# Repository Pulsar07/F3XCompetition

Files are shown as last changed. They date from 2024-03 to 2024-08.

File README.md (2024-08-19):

<div class="PageDoc">

<div class="header">

<div class="headertitle">

<div class="title">

F3X Competition is a tool to provide training measurements and analysis data for F3X model flight classes. 
At the moment it is limited to the F3B/F3G speed task and F3F task, but could be extended later on.

</div>

</div>

</div>

<div class="contents">

<div class="textblock">

# <span id="intro_sec_en" class="anchor"></span> Overview

In many F3X model flight classes there are distance and speed tasks, expecting the model to pass/cross a A- and B-line of a defined distance.
The passing and crossing is supervised by human helpers and signalled by pressing a button indication the valid pass or line crossing.

These procedures are supported by this F3X Competition tool (currently only the F3B/F3G speed task and F3F task).

The F3X Competition tool consist of two main parts:
* the BaseManager 
  * with a rotation/push button signaling device (Control and A-Line-Signal)
  including almost all logic and time measurement module
  * a display to provide flight data and user interface data
  * 2.4GHz radio link to communicate with the B-LineController
* the B-LineController
  * with a push button signaling device (B-Line-Signal)
  * 2.4GHz radio link to communicate with the BaseManager

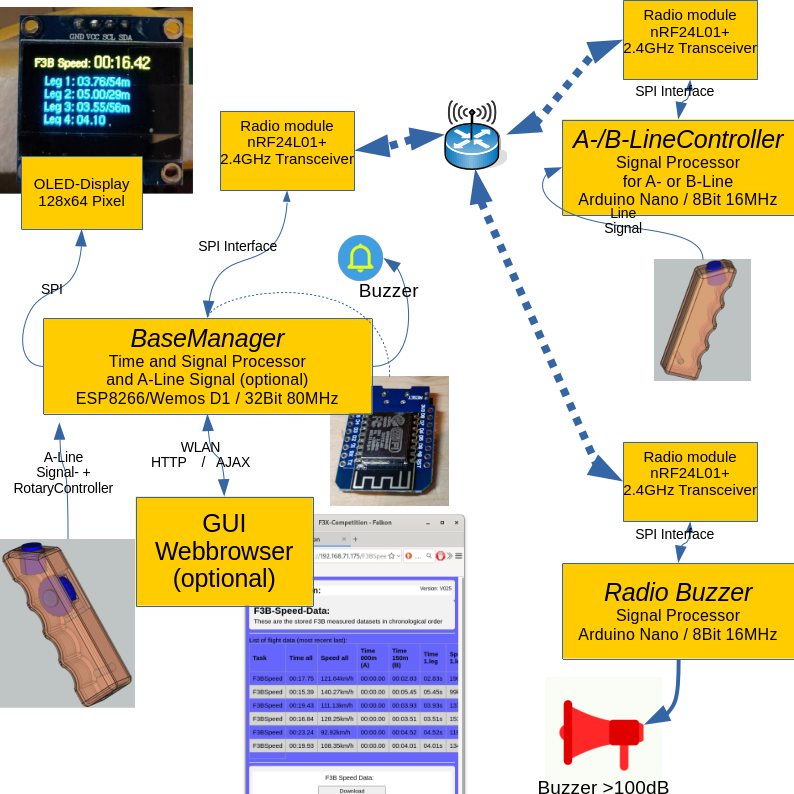
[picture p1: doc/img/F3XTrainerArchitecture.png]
Architektur


# <span id="features_sec_de" class="anchor"></span> Features
* 2.4GHz radio link using 1MHz channel between A-Line and B-Line
* time measurement with accurancy much better than 10ms
* accustic signal on A-Line
* F3B speed task is supported
  * overall time and detailed time and speed per leg is supported
  * dead distances behind the crossing lines are measured optionally and dead distances are supported
  * Loop mode: final signal of one task is the start signal for the next pilot
* F3F task is supported
  * overall time and detailed time and speed per leg is supported
  * dead distances behind the crossing lines are measured optionally and dead distances are supported
  * Loop mode: final signal of one task is the start signal for the next pilot
* integrated battery and charge HW with low battery warning
* firmware/data (BaseManager) can be updated over the air (OTA)
* BaseManager has a small OLED and rotary input device for on field operation
* BaseManager provides a Web-interface to be used for:
  * changes of settings
  * view, manage and download the saved trainings data
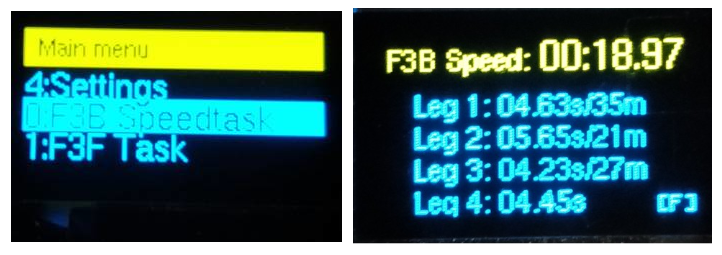
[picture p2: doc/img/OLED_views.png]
OLED


# <span id="hardware_sec_en" class="anchor"></span> Hardware
* Wemos D1 (BaseManager)
* Arduino Nano (B-LineController)
* 2.4GHz nRF24L01+ radio module
* BatteryShield
* LiIon Accu
* RotaryEncoder KY-040
* Push button
* OLED 128x64
* LED

</div>

</div>

</div>

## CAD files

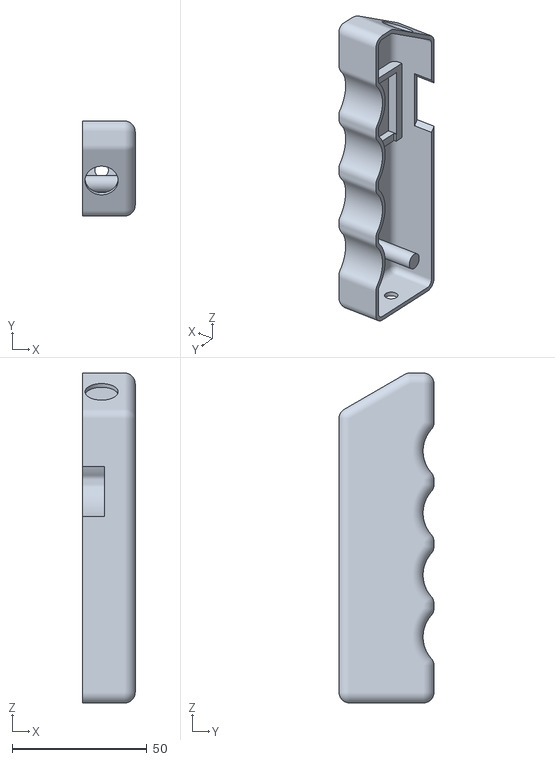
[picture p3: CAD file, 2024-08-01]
CAD/Griff-Griff-Halbschale-A-Line.stl
19.5 x 35.3 x 122.5

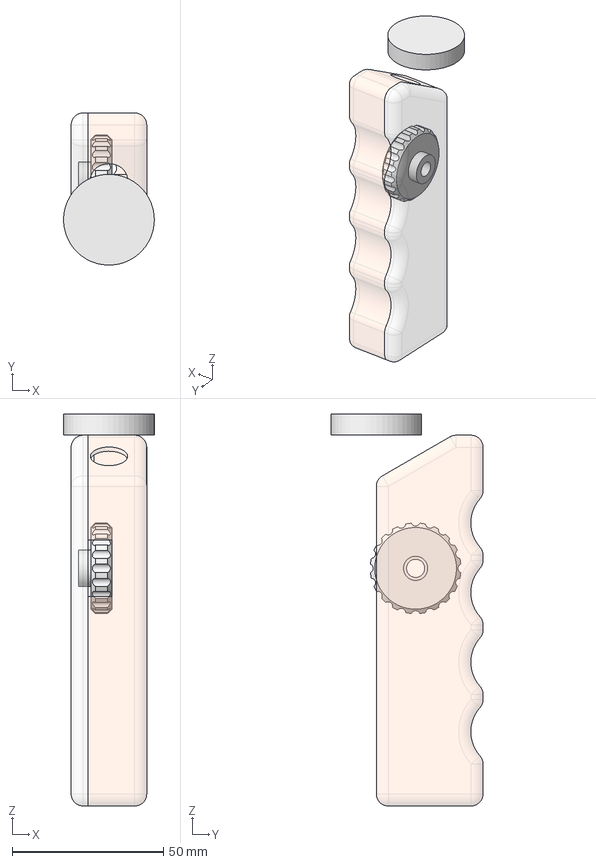
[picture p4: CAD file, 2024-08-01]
CAD/Griff.FCStd
30.0 x 50.3 x 129.5 mm
Griff-Deckel A-Line, mit Nut, Anbauteilen, Aussparungen
Encoder-Rad, roh
Drehrad, gefast, gelocht, geriffelt
Griff-Halbschale A-Line mit Aussparungen und Anbauteilen

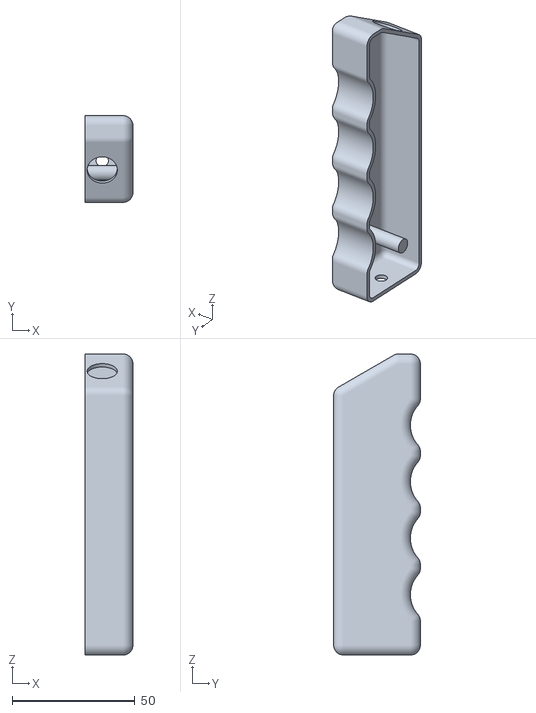
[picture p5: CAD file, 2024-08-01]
CAD/Griff-Griff-Halbschale-B-Line.stl
19.5 x 35.3 x 122.5

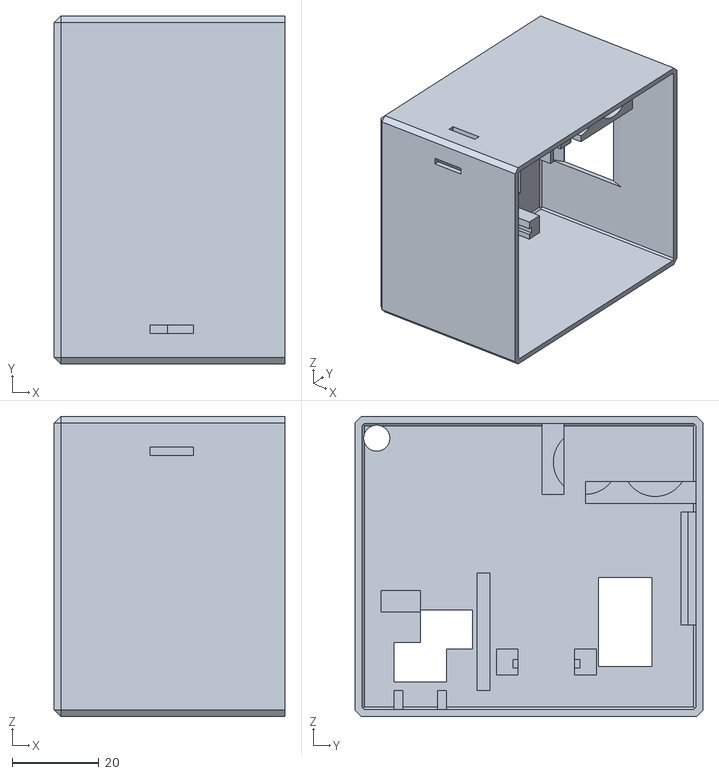
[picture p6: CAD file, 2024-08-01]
CAD/A-Line-Gehäuse.stl
53.0 x 80.0 x 69.0

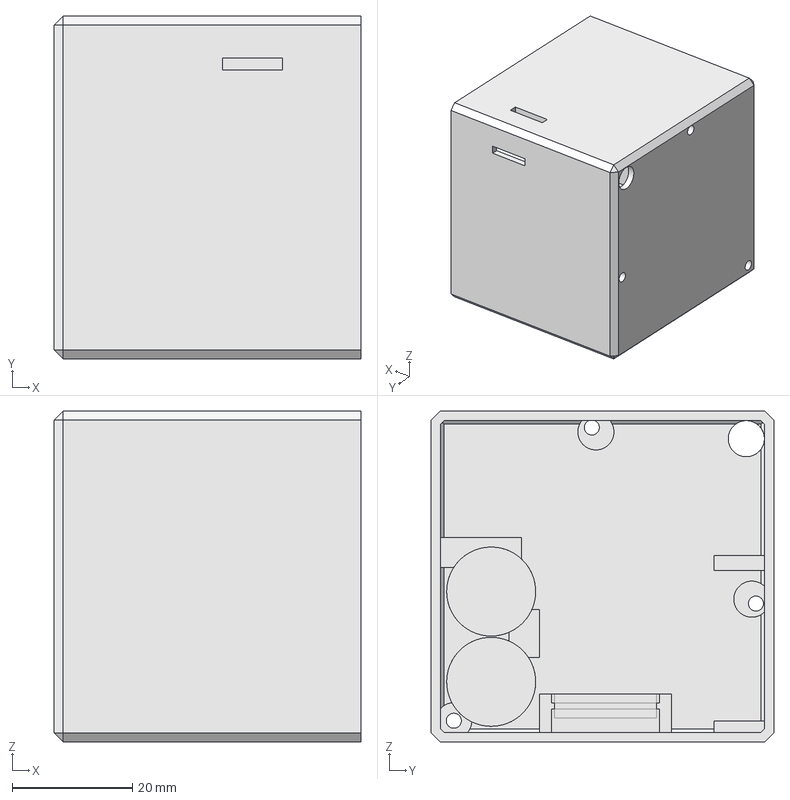
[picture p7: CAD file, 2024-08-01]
CAD/GehäuseF3XTrainer.FCStd
51.0 x 57.0 x 55.0 mm

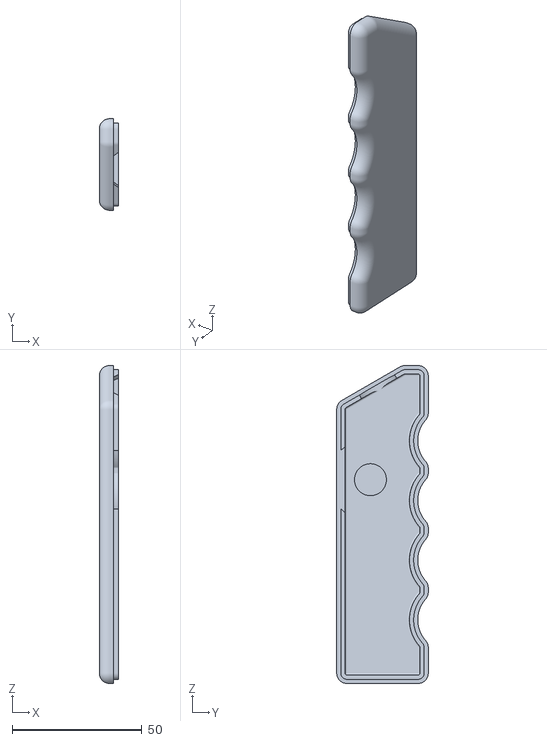
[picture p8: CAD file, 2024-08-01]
CAD/Griff-Deckel-A-Line.stl
7.50 x 35.3 x 122.5

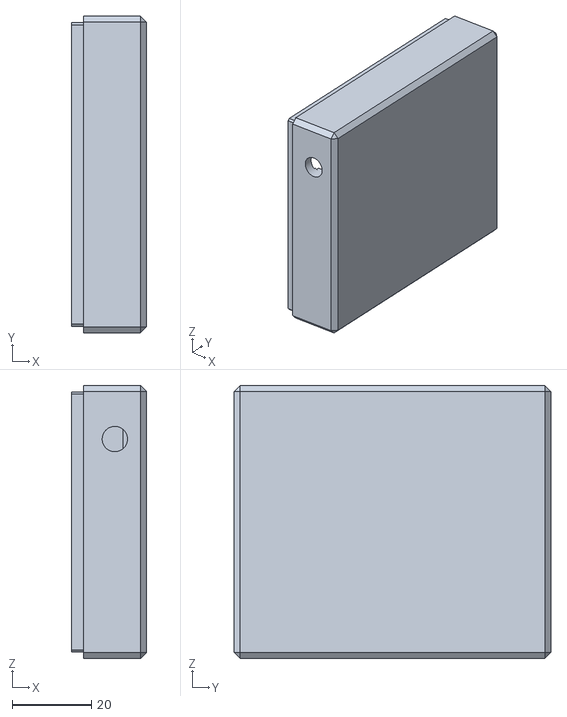
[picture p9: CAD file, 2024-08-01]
CAD/A-Line-Deckel.stl
19.0 x 80.0 x 69.0

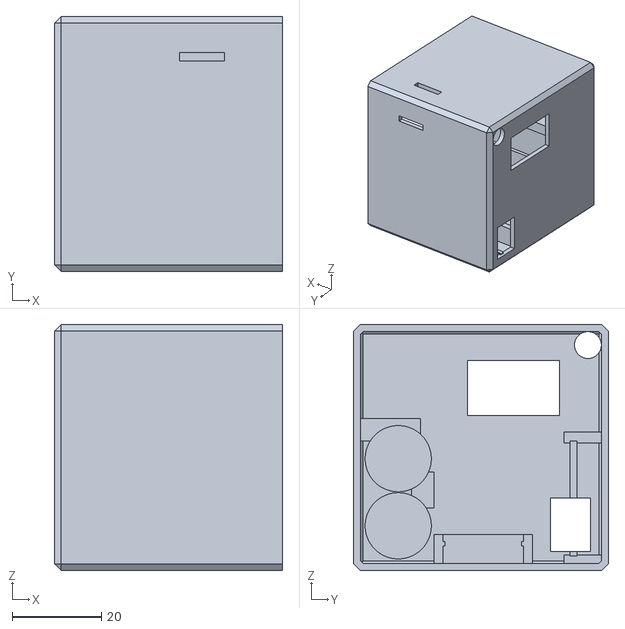
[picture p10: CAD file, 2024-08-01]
CAD/B-Line-Gehäuse.stl
51.0 x 57.0 x 55.0

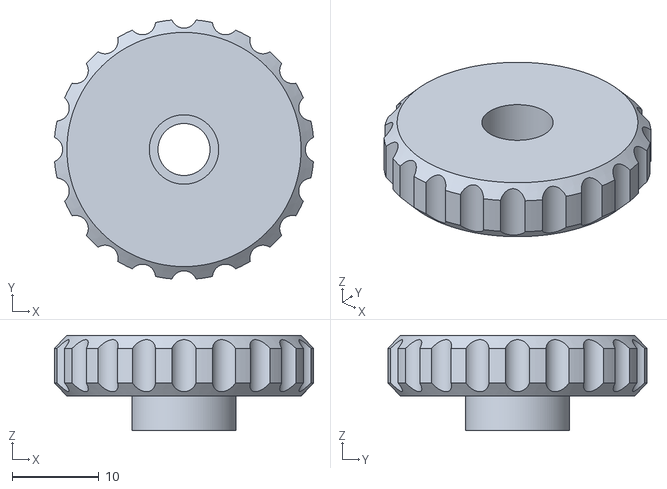
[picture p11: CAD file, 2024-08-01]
CAD/Griff-Drehrad-A-Line.stl
29.9 x 29.9 x 11.0

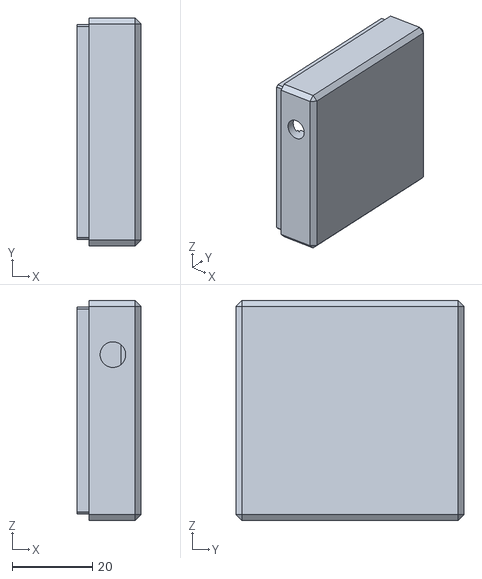
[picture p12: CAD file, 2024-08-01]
CAD/B-Line-Deckel.stl
16.0 x 57.0 x 55.0

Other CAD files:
CAD/RemoteBuzzer-Gehäuse.stl
CAD/Griff-Deckel.stl

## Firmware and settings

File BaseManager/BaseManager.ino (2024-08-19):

/**
 * \file BaseManager.ino
 *
 * \brief tool support trainings data measurement  
 *
 * \author Author: Rainer Stransky
 *
 * \copyright This project is released under the GNU Public License v3
 *          see https://www.gnu.org/licenses/gpl.html.
 * Contact: opensource@so-fa.de
 *
 */

#include <EEPROM.h>
#include <limits.h>
#include <ESP8266WiFi.h>
// #define USE_MDNS
#ifdef USE_MDNS
#include <ESP8266mDNS.h>
#endif
#include <WiFiUdp.h>
#include <ESP8266WebServer.h>
#include <ESP8266httpUpdate.h>
#include <Bounce2.h>
#include <Encoder.h>

#include "Logger.h"
#include "PinManager.h"
#include "LittleFS.h"
#include "Config.h"
#include "F3XFixedDistanceTask.h"
#include "F3XFixedDistanceTaskData.h"
#include "settings.h"

#define USE_RXTX_AS_GPIO  // for usage of rotary encoder instead of Serial

#define APP_VERSION "V035"

/*
Version History
 V011 19.10.2023: RS : pre-version: test web interface enhanced, minor bugs solved, OTA implemented
 V010 18.10.2023: RS : pre-version: initial version for F3B speed task and training data, with web interface only
 V023 26.02.2024: RS : firmware update triggerd on ABaseManager via Einstellungen->3:Update Firmw.;
 V024 08.03.2024: RS : pre version of RF24 channel and power setting via controller and OLED
 V025 13.03.2024: RS : A-line controller with rotary encoder, settings in EEPROM via OLED and Web.
 V026 13.03.2024: RS : Web-pages redesigned
 V027 15.03.2024: RS : Buzzer refactored to PinManager-class to support beep sequences for battery low warning
 V028 18.03.2024: RS : new speed start / back menu added
 V029 19.03.2024: RS : F3B Speed Tasktime is now a config item.
 V030 28.03.2024: RS : Refactoring F3BSpeedTask -> F3XFixedDistanceTask, more consistent time strings and units (CSV)
 V031 04.05.2024: RS : added support for a radio buzzer 
 V032 31.07.2024: RS : F3F Task added, Logger refactored, TaskData handling generalized, address schema of RFTransceiver fixed.
 V033 01.08.2024: RS : Support for F3X Loop Task, finalizing the course will start frame time of next starter automatically
 V034 02.08.2024: RS : nRF24 address scheme modified to support old versions of remote devices 
 V035 19.08.2024: RS : bugfix: buzzer settings not saved, added missing F3F A-Line flyover signal,  long 1.5s finish signals F3F+F3B, 
                       interpreation of F3F Tasktime is now: time between StartTaskSignal and launch time,
                       more precise naming of entities/files: BaseManager, LineController  
*/

/**
Feature list:
* Battery warning
* F3B Speed, F3F Task
*
* ...
*/

static const char myName[] = "BaseM";
static const char MYSEP_STR[] = "~~~";
static const char CMDSEP_STR[] = ",";

// Used Ports as as summary
/*
D0 : RF24-NRF24L01 CE (brown-white)
D1 : OLED-SSD1306 SCL
D2 : OLED-SSD1306 SDA 
D3 : RF24-NRF24L01 CNS (brown) 
D4 : Signalling Button A-Line
D5 : RF24-NRF24L01 SCK (blue-white) 
D6 : RF24-NRF24L01 MISO (green-white)
D7 : RF24-NRF24L01 MOSI (blue)
D8 : BUZZER / LED
D9/RX  : KY-040 Encoder - DT 
D10/TX : KY-040 Encoder - CLK

*/


#define PIN_RF24_CE       D0
#define PIN_OLED_SCL      D1
#define PIN_OLED_SDA      D2
#define PIN_RF24_CNS      D3
#define PIN_SIGNAL_A_LINE D4
#define PIN_RF24_SCK      D5
#define PIN_RF24_MISO     D6
#define PIN_RF24_MOSI     D7
#define PIN_BUZZER_OUT    D8
#define PIN_ENCODER_DT    D9
#define PIN_ENCODER_CLK   D10

#define PIN_BATTERY_IN    A0  // connected wiht R=100kOhm to support V > 3.2V

#define USE_BATTERY_IN_VOLTAGE
#define PERF_DEBUG

// #define NOBUZZ
#ifdef NOBUZZ
#pragma message ("BUZZER IS OFF !!!!!!!!!!!")
#endif
#define BUZZ_TIME_LONG   1500 // course finised
#define BUZZ_TIME_NORMAL  500 // normal turn
#define BUZZ_TIME_SHORT    100 // user info

#include <RFTransceiver.h>
RFTransceiver ourRadio(myName, PIN_RF24_CE, PIN_RF24_CNS); // (CE, CSN)



#ifdef USE_RXTX_AS_GPIO
Encoder ourRotaryEncoder(PIN_ENCODER_DT, PIN_ENCODER_CLK);
#endif

#define RE_MULITPLIER_SLOW 1
#define RE_MULITPLIER_NORMAL 5
long ourRotaryMenuPosition=0;
uint8_t ourRotaryEncoderMultiplier;
static boolean ourREState = true;
static int8_t ourREInversion = 1;
static long ourREOldPos  = 0;

static boolean ourLoopF3XTask = false;
static unsigned long ourLoopF3XPrevCourseTime = 0L;

enum BuzzerSetting {
  BS_ALL = 0, // both buzzers are active 
  BS_BASEMANAGER, // only direct connected BaseManager Buzzer 
  BS_REMOTE_BUZZER, // only remote radio buzzer
  BS_NONE, // no buzzers are active 
  BS_LAST,
};

static boolean ourIsTimeCriticalOperationRunning = false;

enum ToolContext {
  TC_F3XBaseMenu,
  TC_F3XSettingsMenu,
  TC_F3BSpeedTasktimeCfg,
  TC_F3FTasktimeCfg,
  TC_F3FLegLengthCfg,
  TC_F3XRadioChannelCfg,
  TC_F3XRadioPowerCfg,
  TC_F3XInfo,
  TC_F3XRadioInfo,
  TC_F3XMessage,
  TC_F3BSpeedMenu,
  TC_F3BSpeedTask,
  TC_F3FTaskMenu,
  TC_F3FTask,
  TC_F3BDistanceTask,
  TC_F3BDurationTask,
};

#define F3XCONTEXT_HISTORY_SIZE 5
class F3XContext {
  public:
    F3XContext(ToolContext aContext) {
      for (uint8_t i=0; i<F3XCONTEXT_HISTORY_SIZE; i++) {
        myContextHistory[i] = TC_F3XBaseMenu;
      }
      set(aContext);
    }
    void set(ToolContext aContext) {
      logMsg(LOG_MOD_SIG, INFO, String("set context:") + String(aContext));
      
      for (uint8_t i=0; i<F3XCONTEXT_HISTORY_SIZE-1; i++) {
        myContextHistory[i+1] = myContextHistory[i];
      }
      myContextHistory[0] = aContext;
  
      myInfoString="";
      myInfoInt = 0;
      myInfoFloat = 0.0f;
      myIsTaskRunning = false;
    }
    void back() {
      for (uint8_t i=0; i<F3XCONTEXT_HISTORY_SIZE-1; i++) {
        myContextHistory[i] = myContextHistory[i+1];
      }
      myContextHistory[F3XCONTEXT_HISTORY_SIZE-1] = TC_F3XBaseMenu;

      logMsg(LOG_MOD_SIG, INFO, String("back context:") + String(get()));
    }
    ToolContext get() {
      return myContextHistory[0];
    }
    String getInfoString() {
      return myInfoString;
    }
    float getInfoFloat() {
      return myInfoFloat;
    }
    int getInfoInt() {
      return myInfoInt;
    }
    void setInfo(float aArg) {
      myInfoFloat = aArg;
    }
    void setInfo(int aArg) {
      myInfoInt = aArg;
    }
    void setInfo(String aArg) {
      myInfoString = aArg;
    }
  private:
    ToolContext myContextHistory[F3XCONTEXT_HISTORY_SIZE];
    float myInfoFloat;
    int myInfoInt;
    String myInfoString;
    bool myIsTaskRunning;
};

F3XContext ourContext(TC_F3XInfo);

// TC_F3XBaseMenu
const char* ourF3XBaseMenuName = "Main menu";
const char* ourF3XBaseMenu0 = "0:F3B Speedtask";
const char* ourF3XBaseMenu1 = "1:F3F Task";
const char* ourF3XBaseMenu2 = "2:Info";
const char* ourF3XBaseMenu3 = "3:Radio-Info";
const char* ourF3XBaseMenu4 = "4:Settings";
const char* ourF3XBaseMenuItems[] = {ourF3XBaseMenu0, ourF3XBaseMenu1, ourF3XBaseMenu2, ourF3XBaseMenu3, ourF3XBaseMenu4};
const uint8_t ourF3XBaseMenuSize = sizeof(ourF3XBaseMenuItems) / sizeof(char*);;

// TC_F3XSettingsMenu
const char* ourSettingsMenuName = "Settings";
const char* ourSettingsMenu0 = "0:F3B Speed Ttime";
const char* ourSettingsMenu1 = "1:F3F Ttime";
const char* ourSettingsMenu2 = "2:F3F LegLength";
const char* ourSettingsMenu3 = "3:Buzzers setup";
const char* ourSettingsMenu4 = "4:Competition setup";
const char* ourSettingsMenu5 = "5:Radio channel";
const char* ourSettingsMenu6 = "6:Radio power";
const char* ourSettingsMenu7 = "7:Display invert";
const char* ourSettingsMenu8 = "8:Rotary button inv.";
const char* ourSettingsMenu9 = "9:Update firmware";
const char* ourSettingsMenu10 = "10:Update filesystem";
const char* ourSettingsMenu11 = "11:WiFi on/off";
const char* ourSettingsMenu12 = "12:Save settings";
const char* ourSettingsMenu13 = "13:Main menu";
const char* ourSettingsMenuItems[] = {ourSettingsMenu0, ourSettingsMenu1, ourSettingsMenu2, ourSettingsMenu3, ourSettingsMenu4, ourSettingsMenu5, ourSettingsMenu6, ourSettingsMenu7, ourSettingsMenu8, ourSettingsMenu9, ourSettingsMenu10, ourSettingsMenu11, ourSettingsMenu12, ourSettingsMenu13};
const uint8_t ourSettingsMenuSize = sizeof(ourSettingsMenuItems) / sizeof(char*);

// TC_F3BSpeedMenu
const char* ourF3BSpeedMenuName = "F3B Speed";
const char* ourF3BSpeedMenu0 = "0:Start Task";
const char* ourF3BSpeedMenu1 = "1:Loop Task";
const char* ourF3BSpeedMenu2 = "2:Back";
const char* ourF3BSpeedMenuItems[] = {ourF3BSpeedMenu0, ourF3BSpeedMenu1, ourF3BSpeedMenu2};
const uint8_t ourF3BSpeedMenuSize = sizeof(ourF3BSpeedMenuItems) / sizeof(char*);

// TC_F3FTaskMenu
const char* ourF3FTaskMenuName = "F3F Task";
const char* ourF3FTaskMenu0 = "0:Start Task";
const char* ourF3FTaskMenu1 = "1:Loop Task";
const char* ourF3FTaskMenu2 = "2:Back";
const char* ourF3FTaskMenuItems[] = {ourF3FTaskMenu0, ourF3FTaskMenu1, ourF3FTaskMenu2};
const uint8_t ourF3FTaskMenuSize = sizeof(ourF3FTaskMenuItems) / sizeof(char*);


#include "F3XRemoteCommand.h"

#define OLED
#ifdef OLED
#include <U8g2lib.h>
/*
// TFT Display  ST7735S
//
https://github.com/olikraus/u8g2/wiki/u8g2setupcpp#introduction
SCL D1
SDA D2
U8G2_SSD1306_128X64_NONAME_1_HW_I2C(rotation, [reset [, clock, data]]) [page buffer, size = 128 bytes]
U8G2_SSD1306_128X64_NONAME_2_HW_I2C(rotation, [reset [, clock, data]]) [page buffer, size = 256 bytes]
U8G2_SSD1306_128X64_NONAME_F_HW_I2C(rotation, [reset [, clock, data]]) [full framebuffer, size = 1024 bytes]
*/

// U8G2_SSD1306_128X64_NONAME_1_HW_I2C ourOLED(U8G2_R0, U8X8_PIN_NONE, D1, D2);
// #define SSD1306_AZ_Delivery
// supported OLEDs
// OLED 0.96" SSD1306   0,96 Zoll OLED SSD1306 Display I2C 128 x 64 Pixel / AZ-Delivery
#define OLED_FULL_BUFFER
#ifdef OLED_FULL_BUFFER
U8G2_SSD1306_128X64_NONAME_F_HW_I2C ourOLED(U8G2_R0, U8X8_PIN_NONE, PIN_OLED_SCL /*SCL*/, PIN_OLED_SDA /*SDA*/);  
#else
U8G2_SSD1306_128X64_NONAME_1_HW_I2C ourOLED(U8G2_R0, U8X8_PIN_NONE, PIN_OLED_SCL /*SCL*/, PIN_OLED_SDA /*SDA*/);  
#endif
// OLED xxx
// U8G2_SSD1309_128X64_NONAME2_1_HW_I2C ourOLED(U8G2_R0, U8X8_PIN_NONE, PIN_OLED_SCL /*SCL*/, PIN_OLED_SDA /*SDA*/);  

#endif

#define OTA
#ifdef OTA
#include <ArduinoOTA.h>
#endif
 

IPAddress ourApIp(192,168,4,1);
IPAddress ourNetmask(255,255,255,0);
ESP8266WebServer ourWebServer(80);
unsigned long ourSecond = 0;

static configData_t ourConfig;
F3XFixedDistanceTask ourF3BSpeedTask(F3XFixedDistanceTask::F3BSpeedType);
F3XFixedDistanceTaskData ourF3BTaskData(&ourF3BSpeedTask);
F3XFixedDistanceTask ourF3FTask(F3XFixedDistanceTask::F3FType);
F3XFixedDistanceTaskData ourF3FTaskData(&ourF3FTask);
F3XFixedDistanceTask* ourF3XGenericTask = nullptr;
unsigned long ourWlanRoundTripTime=0;
unsigned long ourRadioRequestTime=0;
float ourRadioRoundTripTime=0;
uint8_t ourRadioRequestArg=0;
uint16_t ourRadioCycleSendCnt=0;
uint8_t ourRadioPacketsLossPercent=0;
uint16_t ourRadioCycleRecvCnt=0;
uint16_t ourRadioRoundTripMissed=0;
uint16_t ourRadioRoundtripIdx=0;
int8_t ourRadioPower=-1;
int8_t ourRadioChannel=-1;
int8_t ourRadioDatarate=-1;
boolean ourRadioAck=true;
boolean ourRadioSendSettings=false;
float ourRadioQuality=0.0f;
uint16_t ourRadioStatePacketsMissed=0;
uint16_t ourRadioSignalRoundTrip=0;
boolean ourStartupPhase=true;
F3XRemoteCommand ourRemoteCmd;
uint16_t ourBatteryAVoltage;
uint16_t ourBatteryBVoltage;
uint16_t ourBatteryBVoltageRaw;
uint16_t ourBatteryRemoteSignalRaw;
unsigned long ourTimedReset = 0;
unsigned long ourDialogTimer=0;
String ourDialogString="";

Bounce2::Button ourPushButton = Bounce2::Button();
PinManager ourBuzzer(PIN_BUZZER_OUT);

// =========== some function forward declarations ================

void updateOLED(unsigned long aNow, bool aForce);
void updateOLED(unsigned long aNow);
#ifdef USE_RXTX_AS_GPIO
void resetRotaryEncoder(long aPos=0);
#endif
uint8_t getModulo(long aDivident, uint8_t aDivisor);
void forceOLED(uint8_t aLevel, String aMessage);
void forceOLED(String aHead, String aMessage);
void setDefaultConfig();
void saveConfig();
void takeOLEDScreenshot();


void restartMCs(uint16_t aDelay, bool aRestartOnlyBLine=false) {
  ourRadio.transmit(ourRemoteCmd.createCommand(F3XRemoteCommandType::CmdRestartMC)->c_str(), 20);
  ourRadio.setWritingPipe(2);
  ourRadio.transmit(ourRemoteCmd.createCommand(F3XRemoteCommandType::CmdRestartMC)->c_str(), 20);
  ourRadio.setWritingPipe(0);
  if (!aRestartOnlyBLine) {
    // force a restart of ourself
    ourTimedReset = millis() + aDelay;
  }
}


/*
* send a RF24 command to the 2. pipe (radioBuzzer) 
*/
void radioBuzzer(uint16_t aDura) {
  // logMsg(INFO, String(F("=====> radioBuzzer on:")) + String(aDura)); 
  ourRadio.setWritingPipe(2);
  unsigned long a = millis();
  boolean sendSuccess = ourRadio.transmit(ourRemoteCmd.createCommand(F3XRemoteCommandType::RemoteSignalBuzz, String(aDura))->c_str(), 4);

  if (!sendSuccess) {
    logMsg(LOG_MOD_RADIO, ERROR, String(F("sending RemoteSignalBuzz NOT successsfull. Retransmissions: ")) 
      + String(ourRadio.getRetransmissionCount()));
  }
  logMsg(LOG_MOD_RADIO, INFO, String(F("sending RemoteSignalBuzz in: ") + String((millis() - a)))); 
  ourRadio.setWritingPipe(0);
}

void signalBuzzing(uint16_t aDuration) {
  logMsg(LOG_MOD_SIG, INFO, "ABM: signalBuzzing: " + String(aDuration));
  switch (ourConfig.buzzerSetting) {
    case BS_ALL: // both buzzers are active 
      radioBuzzer(aDuration);
      ourBuzzer.on(aDuration);
      break;
    case BS_BASEMANAGER: // only direct connected BaseManager Buzzer 
      ourBuzzer.on(aDuration);
      break;
    case BS_REMOTE_BUZZER: // only remote radio buzzer
      radioBuzzer(aDuration);
      break;
    case BS_NONE: // no buzzers are active 
      break;
  }
}

void signalAListener() {
  logMsg(LOG_MOD_SIG, INFO, "ABM: signalAListener");
  if (ourF3XGenericTask->getTaskState() == F3XFixedDistanceTask::TaskFinished) {
    // looong signal at final A-Line overfly signalling 1500ms
    signalBuzzing(BUZZ_TIME_LONG);
    if (ourF3XGenericTask->getLoopTasksEnabled()) {
      ourF3XGenericTask->stop();
      ourF3XGenericTask->start();
    }
  } else {
    // default signalling 500ms
    signalBuzzing(BUZZ_TIME_NORMAL);
  }
  switch(ourF3XGenericTask->getType()) {
    case F3XFixedDistanceTask::F3BSpeedType:
      if (ourF3XGenericTask->getTaskState() == F3XFixedDistanceTask::TaskFinished) {
        ourF3BTaskData.writeData();
      }
      break;
    case F3XFixedDistanceTask::F3FType:
      if (ourF3XGenericTask->getTaskState() == F3XFixedDistanceTask::TaskFinished) {
        ourF3FTaskData.writeData();
      }
      break;
  }
}

void signalBListener() {
  logMsg(LOG_MOD_SIG, INFO, "signalBListener");
  signalBuzzing(BUZZ_TIME_NORMAL);
}

/**
  return a leg time literal with the format 12.23s/43m  
*/
char* getLegTimeStr(unsigned long aLegTime,  unsigned long aDelay, uint8_t aDistance, char aSeparator='/') {
  static char buffer[25];
  if (aLegTime != F3X_TIME_NOT_SET) {
    sprintf(&buffer[0],"%02d.%02ds", aLegTime / 1000, aLegTime/10%100); // len=8+7=15
  }
  if (aDelay != 0) {
    sprintf(&buffer[strlen(buffer)],"%c%dm", aSeparator, aDistance); // len=15+8=23+1
  }
  return buffer;
}


/**
  return a time literal with the format Seconds.Centies 12.23s
*/
char* getSCTimeStr(unsigned long aTime, bool aShowUnit=false ) {
  static char buffer[10];
  unsigned long theTime = aTime;
  if (aTime == F3X_TIME_NOT_SET) {
    theTime = 0UL;
  }
  String format= F("%02d.%02d");
  if (aShowUnit) {
    format= F("%02d.%02ds");
  }
  sprintf(&buffer[0],format.c_str(), theTime/1000, theTime/10%100); 
  return buffer;
}


#ifdef OLED
const uint8_t *oledFontLarge;
const uint8_t *oledFontBig;
const uint8_t *oledFontNormal;
const uint8_t *oledFontSmall;
const uint8_t *oledFontTiny;


void setupOLED() {
  ourOLED.begin();
  int oledDisplayHeight = ourOLED.getDisplayHeight(); 
  int oledDisplayWidth = ourOLED.getDisplayWidth(); 
  logMsg(INFO, F("init OLED display: ") + String(oledDisplayWidth) + String(F("x")) + String(oledDisplayHeight)); 
  oledFontLarge  = u8g2_font_helvR12_tr;
  oledFontBig    = u8g2_font_helvR10_tr;
  oledFontNormal = u8g2_font_helvR08_tr;
  oledFontSmall  = u8g2_font_5x7_tr;
  oledFontTiny   = u8g2_font_4x6_tr;
  forceOLED(0, String(F("OLED ok")));
}
#endif

void setupRadio() {
  logMsg(INFO, F("setup RCTTransceiver/nRF24L01")); 
  ourRadio.begin(RFTransceiver::F3XBaseManager);  // set 0 for BaseManager
  logMsg(INFO, F("setup for RCTTransceiver/nRF24L01 successful")); 

  // in the RFTransceiver implementation the default values for the radio settings are defined 
  // for A- and B-Line Manager (Channel:110/Power:HIGH/Datarate:RF24_250KBPS/Ack:true)
  // if the user is changing radio settings, they are save in the EEPROM config ourConfig/loadConfig/saveConfig
  // at startup, these config value are NOT used, to provide in any case a commont radio setting for both sides.
  // Only the BaseManager, stores changed radio settings, boots with the default settings starts a communication with the 
  // B-Line-Manager and sends changed settings via radio  

  ourRadioPower=ourRadio.getPower();
  ourRadioChannel=ourRadio.getChannel();
  ourRadioDatarate = ourRadio.getDataRate();
  ourRadioAck=ourRadio.getAck();

  if (   ourRadioChannel != ourConfig.radioChannel
      || ourRadioPower   != ourConfig.radioPower
    ) {
    ourRadioChannel = ourConfig.radioChannel;
    ourRadioPower = ourConfig.radioPower;
    // force a radio data  CmdSetRadio packets to B-Line
    ourRadioSendSettings=true;
  }
  logMsg(LOG_MOD_WEB, INFO, F("RF24-cfg: (c/p)") + String(ourConfig.radioChannel) + String(F("/")) + String(ourConfig.radioPower)); 

  forceOLED(0, ("RF24 radio started"));
}


void setupLittleFS() {
  if(!LittleFS.begin()){
    logMsg(DEBUG, F("LittleFS: An Error has occurred while mounting LittleFS"));
    forceOLED(0, ("FS not ok"));
    return;
  }
  forceOLED(0, ("FS ok"));
}



void setupWiFi() {
  // first try to connect to the stored WLAN, if this does not work try to
  // start as Access Point
  // strncpy(ourConfig.wlanSsid , DEF_SSID, CONFIG_SSID_L);
  // strncpy(ourConfig.wlanPasswd, DEF_PSK, CONFIG_PASSW_L);
  // strncpy(ourConfig.apPasswd, "12345678", CONFIG_PASSW_L) ;
  if (!ourConfig.wifiIsActive) {
    WiFi.mode(WIFI_OFF) ; // client mode only
    forceOLED(0, (String("WiFi: inactive")));
    delay(1500);
    return;
  }

  if (String(ourConfig.wlanSsid).length() != 0 ) {
    WiFi.persistent(false);
    WiFi.mode(WIFI_STA) ; // client mode only
    WiFi.begin(ourConfig.wlanSsid, ourConfig.wlanPasswd);

    logMsg(DEBUG, String(F("Connecting to ")) + ourConfig.wlanSsid);
    int connectCnt = 0;
    while (WiFi.status() != WL_CONNECTED && connectCnt++ < 20) {
      delay(500);
    }
  }

  if (WiFi.status() == WL_CONNECTED) {
    logMsg(INFO, F("success!"));
    logMsg(LOG_MOD_WEB, INFO, F("IP Address is: ") + WiFi.localIP().toString());
    forceOLED(0, (String("WiFi: ") + WiFi.localIP().toString()));
  } else {
    logMsg(INFO, String(F("cannot connect to SSID :")) + ourConfig.wlanSsid);
    WiFi.mode(WIFI_AP) ; // client mode only
  }
  if (WiFi.status() != WL_CONNECTED) {
    logMsg(INFO, String(F("Starting WiFi Access Point with  SSID: ")) + ourConfig.apSsid);
      forceOLED(0, String(("Start WiFi-AP: ") + String(ourConfig.apSsid)));
      delay(1000);
    WiFi.softAPConfig(ourApIp, ourApIp, ourNetmask);    //Password length minimum 8 char
    boolean res = WiFi.softAP(ourConfig.apSsid, ourConfig.apPasswd, 3, 0, 1);    //Password length minimum 8 char, channel, hidden, #clients
    if(res ==true) {
      IPAddress myIP = WiFi.softAPIP();
      logMsg(INFO, F("AP setup done!"));
      logMsg(INFO, String(F("Host IP Address: ")) + myIP.toString());
      logMsg(INFO, String(F("Please connect to SSID: ")) + String(ourConfig.apSsid) + String(F(", PW: ")) + ourConfig.apPasswd);
      forceOLED(0, String(F("WiFi AP-SSID: ")) + String(ourConfig.apSsid) + String(F(" IP: ")) + myIP.toString());
      delay(1000);
    } else {
      forceOLED(0, String("WiFi: not started"));
      delay(1000);
    }
  }
  #ifdef USE_MDNS
  if (!MDNS.begin("f3x", WiFi.localIP())) {             
    logMsg(LOG_MOD_NET, ERROR, "Error starting mDNS");
  } else {
    logMsg(LOG_MOD_NET, INFO, "mDNS started");
  }
  #endif
}

String getWiFiIp(String* ret) {
  if (WiFi.status() == WL_CONNECTED) {
    ret->concat(WiFi.localIP().toString());
  } else {
    ret->concat(String(ourConfig.apSsid));
    ret->concat(String(F("/")));
    ret->concat(WiFi.softAPIP().toString());
  }
  return *ret;
}

// End: WIFI WIFI WIFI

// Start: WEBSERVER WEBSERVER WEBSERVER 
// =================================
// web server functions
// =================================

const int led = 13;
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
void loop()
{
  static unsigned long next = 0;
  static unsigned long lastslow = 0;
  unsigned long now = millis();

  #ifdef PERF_DEBUG
  unsigned long lnow;
  boolean isSlow = false;
  if ((now - lastslow) > 200) {
    logMsg(LOG_MOD_PERF, WARNING, String(F("slow last loop:")) + String(now-lastslow));
    isSlow = true;
  }
  lastslow = now;
  #endif

  perfCheck(&updatePushButton, "time push button", now);

  perfCheck(&updateBuzzer, "time buzzer", now);

  perfCheck(&updateF3XTask, "time speedtask", now);

  perfCheck(&updateRadio, "time radio", now);

  perfCheck(&updateWebServer, "time webserver", now);

  perfCheck(&updateBatterySupervision, "time battery supervision", now);

  perfCheck(&updateTimedEvents, "time timedEvents", now);
  
  #ifdef OLED 
  perfCheck(&updateOLED, "time oled display", now);
  #endif

  #ifdef USE_RXTX_AS_GPIO
  perfCheck(&updateRotaryEncoder, "time rotary encoder", now);
  #endif


  if (WiFi.status() == WL_CONNECTED) {
    #ifdef OTA
    ArduinoOTA.handle();
    #endif
    #ifdef USE_MDNS
    MDNS.update();
    #endif
  }

  if (now >= next) {
    ourSecond++;
    next = now + 1000;
  } else {
    return;
  }

  if (ourSecond > 5) {
    ourStartupPhase = false;
  }
}

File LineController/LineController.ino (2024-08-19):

#include <EEPROM.h>
#include <Bounce2.h>
#include <Logger.h>
#include "PinManager.h"
#include "Config.h"

#define APP_VERSION F("V032")

static const char myName[] = "B-Line";


// Used Ports as as summary for a Arduino Nano
/*
2 : Signalling Button B-Line
3 : Feedback LED B-Line-Controller
8 : 
9 : RF24-NRF24L01 (CE brownwhite)
10 : RF24-NRF24L01 (CNS brown)
11 : RF24-NRF24L01 MOSI (blue)
12 : RF24-NRF24L01 MISO (green-white)
13 : RF24-NRF24L01 SCK  (blue-white)
A7 : Analog Battery in
*/


#define PIN_SIGNAL_BRAVO   2
#define PIN_LED            3
#define PIN_SIGNAL_ALFA    4
#define PIN_SIGNAL_CHARLIE 5
#define PIN_SIGNAL_DELTA   6
#define PIN_SIGNAL_ECHO    7
#define PIN_SIGNAL_FOXTROT 8
#define PIN_RF24_CE       9
#define PIN_RF24_CNS     10
#define PIN_RF24_MOSI    11
#define PIN_RF24_MISO    12
#define PIN_RF24_SCK     13
#define PIN_BATTERY_IN   A7


static configData_t ourConfig;

#include <RFTransceiver.h>
RFTransceiver ourRadio(myName, PIN_RF24_CE, PIN_RF24_CNS); // (CE, CNS)
    
unsigned long ourSecond = 0;


#include <F3XRemoteCommand.h>

F3XRemoteCommand ourRemoteCmd;
unsigned long ourTimedReset = 0;
unsigned long ourTimedResponse = 0;
uint16_t ourBatteryVoltage=0;
uint16_t ourBatteryVoltageRaw=0;


Bounce2::Button* ourSignalButtons[6];
Bounce2::Button ourSignalButton = Bounce2::Button();

void(* resetFunc) (void) = 0;  //declare reset function at address 0

uint8_t ourSignalBCounter=0;

void saveConfig() {
  logMsg(INFO, F("saving config to EEPROM "));   

  for(int i=0; i<CONFIG_VERSION_L;i++) {
    EEPROM.write(P_VERSION+i, ourConfig.version[i]);
  }
  EEPROM.put(P_BAT_CALIBRATION, ourConfig.batCalibration);
}

void setDefaultConfig() {
  logMsg(INFO, F("setting default config to EEPROM "));   
  // Reset EEPROM bytes to '0' for the length of the data structure
  strncpy(ourConfig.version , CONFIG_VERSION, CONFIG_VERSION_L);
  ourConfig.batCalibration = 1.0f;
  saveConfig();
}


void loadConfig() {
  logMsg(INFO, F("loading config from EEPROM "));   
  // Loads configuration from EEPROM into RAM
  for(int i=0; i<CONFIG_VERSION_L;i++) {
    ourConfig.version[i] = EEPROM.read(P_VERSION+i);
  }
  EEPROM.get(P_BAT_CALIBRATION, ourConfig.batCalibration);

  // config was never written to EEPROM, so set the default config data and save it to EEPROM
  if ( String(CONFIG_VERSION) == ourConfig.version ) {
     // ok do nothing, this is the expected version
  } else if (String("XYZ_") == ourConfig.version ) {
     // ok do nothing, this is the expected version
    logMsg(WARNING, String(F("old but compatible config version found: ")) + String(ourConfig.version));
  } else {
    logMsg(WARNING, String(F("unexpected config version found: ")) + String(ourConfig.version));
    setDefaultConfig();
  }
}


void setupConfig() {
  loadConfig();
}

void setupRF() {
  ourRadio.begin(RFTransceiver::F3XBLineController);
  logMsg(INFO, F("setup for RCTTransceiver/nRF24L01 successful "));   
}


#define USE_BATTERY_IN_VOLTAGE
#ifdef USE_BATTERY_IN_VOLTAGE
// primary battery voltage handling (LiIon Accu of battery shield)
void  setupBatteryIn() {
  logMsg(INFO, String(F("setup pin ")) + String(PIN_BATTERY_IN) + F(" for battery voltage input"));   
  pinMode(PIN_BATTERY_IN, INPUT);
}

PinManager ourLED(PIN_LED);

void updateBatteryIn(unsigned long aNow) {
  static unsigned long last = 0;
  #define BAT_IN_CYCLE 3000
  #define V_REF 5000
  // DEFAULT 5127mV with USB connected
  // DEFAULT 4959mv with battery shield

  if (aNow > last) {
    last = aNow + BAT_IN_CYCLE;
    ourBatteryVoltageRaw = analogRead(PIN_BATTERY_IN);
    // Arduino Nano 5V can read 5V on analog in
    ourBatteryVoltage=((float) ourBatteryVoltageRaw)/1024.0*V_REF*ourConfig.batCalibration;
  
    logMsg(INFO, String(F("battery voltage: ")) + String(ourBatteryVoltage) + String("/") + String(ourBatteryVoltageRaw));
    
    // logMsg(INFO, "sending TESTEST  SignalB");
    // if (!ourRadio.transmit(ourRemoteCmd.createCommand(F3XRemoteCommandType::SignalB, String(ourSignalBCounter))->c_str(), 5)) {
    //   logMsg(ERROR, String(F("Test Signal was NOT send: ")));
    // }

  } 

}
#endif

void setupSignallingButton() {
  // BUTTON SETUP 
  // INPUT_PULLUP for bare ourSignalButton connected from GND to input pin
  ourSignalButtons[0] = new Bounce2::Button();
  ourSignalButtons[0]->attach(PIN_SIGNAL_ALFA, INPUT_PULLUP );
  ourSignalButtons[1] = new Bounce2::Button();
  ourSignalButtons[1]->attach(PIN_SIGNAL_BRAVO, INPUT_PULLUP );
  ourSignalButtons[2] = new Bounce2::Button();
  ourSignalButtons[2]->attach(PIN_SIGNAL_CHARLIE, INPUT_PULLUP );
  ourSignalButtons[3] = new Bounce2::Button();
  ourSignalButtons[3]->attach(PIN_SIGNAL_DELTA, INPUT_PULLUP );
  ourSignalButtons[4] = new Bounce2::Button();
  ourSignalButtons[4]->attach(PIN_SIGNAL_ECHO, INPUT_PULLUP );
  ourSignalButtons[5] = new Bounce2::Button();
  ourSignalButtons[5]->attach(PIN_SIGNAL_FOXTROT, INPUT_PULLUP );

  for (int i=0; i<6; i++) {
    // DEBOUNCE INTERVAL IN MILLISECONDS
    ourSignalButtons[i]->interval(10);
    // INDICATE THAT THE LOW STATE CORRESPONDS TO PHYSICALLY PRESSING THE BUTTON
    ourSignalButtons[i]->setPressedState(LOW); 
  }
}
  
void setupLog(const char* aName) {
  Logger::getInstance().setup(aName);
  Logger::getInstance().doSerialLogging(true);
  Logger::getInstance().setLogLevel(LOG_MOD_ALL, DEBUG);
  Logger::getInstance().setLogLevel(LOG_MOD_RADIO, DEBUG);
}

void setup() {
  // Open default serial to dump config to
  Serial.begin(115200);
  while (!Serial) delay(10); // wait for serial monitor
  delay(1000);
  Serial.println();
  Serial.println("BRemoteSignalling");

  setupLog(myName);

  logMsg(INFO, String(F("B-Line Remote Signalling: ")) + String(APP_VERSION));
 
  setupConfig();

  analogReference(DEFAULT);
  // DEFAULT 5127mV with USB connected
  // DEFAULT 4959mv with battery shield

   
  #ifdef USE_BATTERY_IN_VOLTAGE
  setupBatteryIn();
  #endif

  setupRF();
  ourRemoteCmd.begin();

  setupSignallingButton();
  
  // all ok
  ourLED.pattern(7,100,100,100,100,100,100,100);
}


void handleButtonEvents(unsigned long aNow) { 
  for (int i=0; i<6; i++) {
    // DEBOUNCE INTERVAL IN MILLISECONDS
    ourSignalButtons[i]->update();
  }

  for (int i=0; i<6; i++) {
    if ( ourSignalButtons[i]->pressed() ) {
      logMsg(INFO, "SignalButton pressed :" + String(++ourSignalBCounter));
    
      logMsg(INFO, "sending SignalB");
      ourRadio.transmit(ourRemoteCmd.createCommand(F3XRemoteCommandType::SignalB, String(ourSignalBCounter))->c_str(), 5);
      ourLED.on(400);
    }
  }
}
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

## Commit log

2024-03-07 V024 08.03.2024: RS : pre version of RF24 channel and power setting via controller and OLED
    [F3BSpeedData.csv]
2024-03-28 V029 19.03.2024: RS : F3B Speed Tasktime is now a config item. V030 28.03.2024: RS : Refactoring F3BSpeedTask -> F3XFixedDistanceTask, more consistent time strings and units (CSV)
    [F3BSpeedData.csv]
2024-05-04 V031 04.05.2024: RS : added support for a radio buzzer
    [ABaseManager.ino, RadioBuzzer.ino]
2024-08-01 V032 31.07.2024: RS : F3F Task added, Logger refactored, TaskData handling generalized, address schema of RFTransceiver fixed
    [F3BSpeedData.csv]
2024-08-01 CAD of housing added
    [A-Line-Deckel.stl, A-Line-Gehäuse.stl, B-Line-Deckel.stl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]
2024-08-01 V033 01.08.2024: RS : Support for F3X Loop Task, finalizing the course will start frame time of next starter automatically
2024-08-02 V034 02.08.2024: RS : nRF24 address scheme modified to support old versions of remote devices
2024-08-19 V035 19.08.2024: RS : bugfix: buzzer settings not saved, added missing F3F A-Line flyover signal, long 1.5s finish signals F3F+F3B, interpreation of F3F Tasktime is now: time between StartTaskSignal 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
    [F3BSpeedData.csv, F3FTaskData.csv]
